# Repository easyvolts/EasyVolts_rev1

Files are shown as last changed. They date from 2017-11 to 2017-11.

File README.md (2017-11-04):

# EasyVolts_rev1
repository for EasyVolts_rev1 device. EasyVolts is a tiny variable power supply with embedded "USB-to-serial" adapter for both UART and RS-485 interfaces which is controlled and powered entirely by USB (over Virtual COM port). It's not only a simple and convenient tool, but it also can be used as a universal bridge between PC software and the "real" world (for example it can be very handy in smart home systems where RS485 and 12v power supply are widely used). This project failed campaign on the IndieGoGo (https://www.indiegogo.com/projects/easyvolts-usb-powered-and-controlled-power-supply#/) so now its sources are made open to share my expirience and ideas among hobbyists.

Hopefully, in future I'll try to launch next generation of the project, with output voltage up to 24v, configurable GPIO/PWM outputs and USB3.0 support (it would be good to have more power). For more details check my web site www.easyvolts.com

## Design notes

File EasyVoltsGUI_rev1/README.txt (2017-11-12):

EasyVoltsGUI is a convenient UI for EasyVolts device. It provides convenient setup of voltage and current limit and easily readable measured load voltage and current.
This is a Python3.5.2 project. UI is build with help of wxFormBuilder 3.6.0 (*.fbp file). Generated by the builder software in in EasyVoltsGUI.py file. Business logic is locted in EasyVoltsGUI.pyw file.

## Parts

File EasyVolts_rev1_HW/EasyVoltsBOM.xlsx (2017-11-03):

Value | RefDes | Pattern | Name
0.2 | R8 | RES_0805 | RES_0805
100nF 25v | C5 | CAP_0603 | CAP_0603
100nF 25v | C6 | CAP_0603 | CAP_0603
100nF 25v | C7 | CAP_0603 | CAP_0603
100nF 25v | C8 | CAP_0603 | CAP_0603
100nF 25v | C9 | CAP_0603 | CAP_0603
100uF 25v | C1 | CAPAE-6.6x6.6h7.9 | CAPAE_6.6x6.6h7.9
10uF 10v | C4 | CAP_1206 | CAP_1206
10uF 25v | C2 | CAP_1206 | CAP_1206
10uF 25v | C3 | CAP_1206 | CAP_1206
1k | R7 | RES_0603 | RES_0603
1k 1% | R1 | RES_0603 | RES_0603
1k 1% | R3 | RES_0603 | RES_0603
1k 1% | R5 | RES_0603 | RES_0603
1k 1% | R9 | RES_0603 | RES_0603
33uH | L1 | SRN6045 | SRN6045
3k3 1% | R2 | RES_0603 | RES_0603
3k3 1% | R4 | RES_0603 | RES_0603
3k3 1% | R6 | RES_0603 | RES_0603
3k3 1% | R10 | RES_0603 | RES_0603
3k3 1% | R11 | RES_0603 | RES_0603
green | D3 | HSM-C170 | HSMQ-C170
NC | J2 | HDR-1x5T/1.27/6x2 | GRPB051VWVN
 | D1 | DIOM_5.4x3.62 | SS24
 | D2 | DIOM_5.1x2.67 | SS12
 | D4 | SOT23 | PESD2CAN
NC | J1 | HDR-1x6T/2.54/15x2 | 644456-6
 | J3 | MC32603 | MC32603
 | Q1 | SOT23 | IRLML9301
 | Q2 | SOT23 | IRLML6346
 | U1 | SOIC-14/150mil | PIC16F1455_SL
 | U2 | SOIC-8/150mil | ISL31472

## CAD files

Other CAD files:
EasyVolts_rev1_MPLAB.X/dist/default/production/EasyPowerUSB.X.production.obj

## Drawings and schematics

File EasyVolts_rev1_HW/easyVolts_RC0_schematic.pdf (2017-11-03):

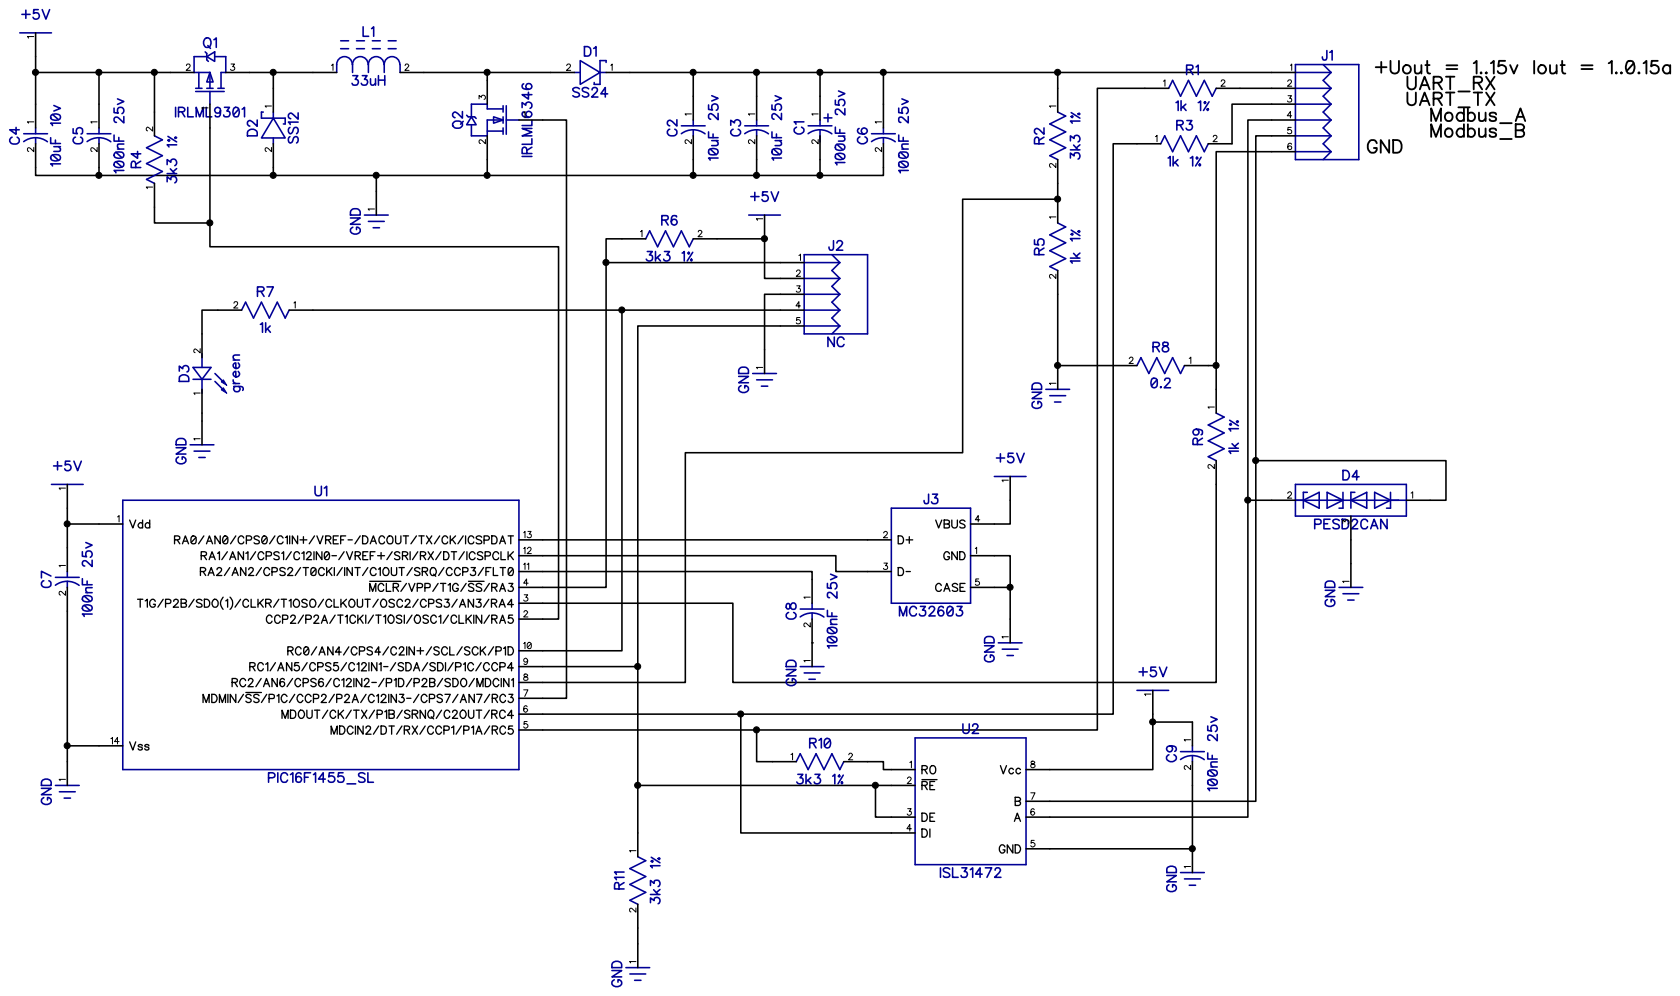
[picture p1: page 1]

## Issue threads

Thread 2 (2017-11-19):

USB2.0 USB Power limitation

tigerwang202, 2017-11-19:
Due to 500mA maximum current limitation from USB 2.0 specification, the Max output current  1A is impossible, unless using an auxiliary 5v power supply.

easyvolts, 2017-11-19:
This is not correct. 1a current is reachable when EasyVolts is in stepDown mode (output voltage is <5v). For example at 1v8 output voltage 1a can be reached (max input power is 2.5w, output power at 1v8 can be 1.8w = 1v8*1a).

tigerwang202, 2017-11-20:
So we need some current limitation method to make sure the VBus current doesn't exceed specification, maybe current monitor(like TI's INA180) connected to MCU's ADC channel?

easyvolts, 2017-11-20:
It's already in the code. Software monitors current (by measuring a voltage on the shunt resistor) and starts reducing output voltage when current goes higher than the limit. The limit can be set by iXXX\r\n command over terminal. If the user tries to set too high power limit - it will be limited inside of the firmware to keep output power <=2.2w(don't remember the exact value). So power consumption from USB is limited. There is only one detail that could be improved - efficiency of the system is not the same for different output voltages, so it would be good to test efficiency in complete output voltage range to create a table that would specify max output power for each output voltage taking into account efficiency of the DCDC. This would guaranty that we will limit power consumption from USB at an appropriate level.

Closed 2017-11-26.

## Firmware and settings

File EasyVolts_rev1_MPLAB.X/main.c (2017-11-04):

/*******************************************************************************
Copyright 2016 Microchip Technology Inc. (www.microchip.com)

Licensed under the Apache License, Version 2.0 (the "License");
you may not use this file except in compliance with the License.
You may obtain a copy of the License at

    http://www.apache.org/licenses/LICENSE-2.0

Unless required by applicable law or agreed to in writing, software
distributed under the License is distributed on an "AS IS" BASIS,
WITHOUT WARRANTIES OR CONDITIONS OF ANY KIND, either express or implied.
See the License for the specific language governing permissions and
limitations under the License.

To request to license the code under the MLA license (www.microchip.com/mla_license), 
please contact mla_licensing@microchip.com
*******************************************************************************/
// This software implements EasyVolt logic (composit USB CDC device made of 2 
// CDC ACM profiles, one to control power converter, second - to be used as 
// USB-UART/RS485 converter).
// Created by: Valerii Proskurin.
// Date: Feb 2017. 

/** INCLUDES *******************************************************/
#include "system.h"

#include "app_uart_usb_utils.h"

#include "usb.h"
#include "usb_device.h"
#include "usb_device_cdc.h"
#include "mcc_generated_files/mcc.h"
#include <stdlib.h>

//#define PWM_TEST
#define PWM_PERIOD              (188)// (333)//142kHz. (283)//166kHz, (237) //200KHz, (187)//250kHz, (93)//500KHz,
#define PWM_PERIOD_LIMIT        (PWM_PERIOD)

#define MAX_POWER_mWt           (2400000U)

#define MAX_UOUT_mV             (15000U)
#define MIN_UOUT_mV             (0U)

#define MAX_IOUT_mA             (1000U)
#define MIN_IOUT_mA             (0U)

uint8_t PwmDutyCycleVoltageLimit = 0, PwmDutyCycleCurrentLimit = 0;
volatile uint16_t Uadc = 0, Iadc = 0;
uint16_t Iadc_limit = 0, Uadc_target = 0;

int32_t MAIN_Uout_target_mV = 0;
int32_t MAIN_Iout_limit_mA = 500;

static uint16_t MAIN_Uout_mV = 0;
static uint16_t MAIN_Iout_mA = 0;
static int8_t MAIN_ovcFlag = 0, MAIN_upConverterFlag = 0;

static uint8_t readBuffer[CDC_DATA_OUT_EP_SIZE];
static uint8_t writeBuffer[CDC_DATA_IN_EP_SIZE];
static uint8_t writeStatusBuffer[CDC_DATA_IN_EP_SIZE];
static uint8_t cmdRxBuffer[CDC_DATA_OUT_EP_SIZE];

static const uint8_t errorMsg[] = "Wrong cmd!\r\n";
static const uint8_t okMsg[] = "OK\r\n";

static uint8_t USB_Out_Buffer[CDC_DATA_OUT_EP_SIZE];
static uint8_t RS232_Out_Data[CDC_DATA_IN_EP_SIZE];
unsigned char  NextUSBOut;
unsigned char  NextUSBOut;
unsigned char  LastRS232Out;  // Number of characters in the buffer
unsigned char  RS232cp;       // current position within the buffer
unsigned char  RS232_Out_Data_Rdy = 0;

//we use stepDown for voltages 0..5v, stepUp for 5..15v
void main_switchStepUp_Down(int32_t Uout_mV)
{
   //disable power
   RA5_SetHigh();
   //adjust PWM
   if(Uout_mV <= 4500) { 
        PwmDutyCycleVoltageLimit = (PWM_PERIOD*(350+Uout_mV))/(5000);//use larger PWM due to losses in coil and diod
        PWM2_LoadDutyValue(0);
        PWM2CON = 0xD0; //active LOW
        APFCON = 0x04;
        MAIN_upConverterFlag = 0;
    } else if(Uout_mV <= 4850) {
        PwmDutyCycleVoltageLimit = 1;
        PWM2_LoadDutyValue(0);
        PWM2CON = 0xC0; //active HIGH
        APFCON = 0x00;
        MAIN_upConverterFlag = 1;
        RA5_SetLow();//enable power output
    } else {
        PwmDutyCycleVoltageLimit = 2 + ((PWM_PERIOD*(Uout_mV - 4850))/(Uout_mV));
        PWM2_LoadDutyValue(0);
        PWM2CON = 0xC0; //active HIGH
        APFCON = 0x00;
        MAIN_upConverterFlag = 1;
        RA5_SetLow();//enable power output
    }
}

void main_CDC_to_RS485_Initialize()
{   
    unsigned char i;
    
    line_coding2.bCharFormat = 0;
    line_coding2.bDataBits = 8;
    line_coding2.bParityType = 0;
    line_coding2.dwDTERate = 9600;

// 	 Initialize the arrays
	for (i=0; i<sizeof(USB_Out_Buffer); i++)
    {
		USB_Out_Buffer[i] = 0;
    }

	NextUSBOut = 0;
	LastRS232Out = 0;
}

#define mDataRdyUSART()         PIR1bits.RCIF
#define mTxRdyUSART()           TXSTAbits.TRMT

void main_CDC_to_RS485_Tasks()
{
    /* If the USB device isn't configured yet, we can't really do anything
     * else since we don't have a host to talk to.  So jump back to the
     * top of the while loop. */
    if( USBGetDeviceState() < CONFIGURED_STATE )
    {
        return;
    }

    /* If we are currently suspended, then we need to see if we need to
     * issue a remote wakeup.  In either case, we shouldn't process any
     * keyboard commands since we aren't currently communicating to the host
     * thus just continue back to the start of the while loop. */
    if( USBIsDeviceSuspended()== true )
    {
        return;
    }

//    /* Check to see if there is a transmission in progress, if there isn't, then
//     * we can see about performing an echo response to data received.
//     */
//    if( USBUSARTIsTxTrfReady2() == true)
//    {
//        uint8_t i;
//        uint8_t numBytesRead;
//
//        numBytesRead = getsUSBUSART2(readBufferRS485, sizeof(readBufferRS485));
//
//        //for test only!!!!
//        if(numBytesRead > 0)
//        {
//            memcpy(writeBufferRS485,readBufferRS485, numBytesRead);
//            /* send out the "echo" data now.
//             */
//            putUSBUSART2(writeBufferRS485,numBytesRead);
//        }
//    }

    if (RS232_Out_Data_Rdy == 0)  // only check for new USB buffer if the old RS232 buffer is
	{						      // empty.  This will cause additional USB packets to be NAK'd
		LastRS232Out = getsUSBUSART2(RS232_Out_Data,64); //until the buffer is free.
		if(LastRS232Out > 0)
		{
			RS232_Out_Data_Rdy = 1;  // signal buffer full
			RS232cp = 0;  // Reset the current position
            IO_RC1_SetHigh(); //Set TXE signal for RS485
		} else {
            if(mTxRdyUSART()) IO_RC1_SetLow(); //Reset TXE signal for RS485
        }
	}

    
    //Check if one or more bytes are waiting in the physical UART transmit
    //queue.  If so, send it out the UART TX pin.
	if(RS232_Out_Data_Rdy && mTxRdyUSART())
	{
	        //Hardware flow control not being used.  Just send the data.
    		USART_putcUSART(RS232_Out_Data[RS232cp]);
    		++RS232cp;
    		if (RS232cp == LastRS232Out) {
                RS232_Out_Data_Rdy = 0;
            }
	}

    //Check if we received a character over the physical UART, and we need
    //to buffer it up for eventual transmission to the USB host.
	if(mDataRdyUSART() && (NextUSBOut < (CDC_DATA_OUT_EP_SIZE - 1)))
        {
		USB_Out_Buffer[NextUSBOut] = USART_getcUSART();
		++NextUSBOut;
		USB_Out_Buffer[NextUSBOut] = 0;
	}

    //Check if any bytes are waiting in the queue to send to the USB host.
    //If any bytes are waiting, and the endpoint is available, prepare to
    //send the USB packet to the host.
	if((USBUSARTIsTxTrfReady2()) && (NextUSBOut > 0))
	{
		putUSBUSART2(&USB_Out_Buffer[0], NextUSBOut);
		NextUSBOut = 0;
	}
    
    CDCTxService2();
}


void main_SetDcDcRegulator(int32_t * pU_mV, int32_t * pI_mA)
{
    //limit voltage
    if((*pU_mV) > MAX_UOUT_mV) (*pU_mV) = MAX_UOUT_mV;
    if((*pU_mV) < MIN_UOUT_mV) (*pU_mV) = MIN_UOUT_mV;
    //limit current
    if((*pI_mA) > MAX_IOUT_mA) (*pI_mA) = MAX_IOUT_mA;
    if((*pI_mA) < MIN_IOUT_mA) (*pI_mA) = MIN_IOUT_mA;
    
    //limit DC-DC power due to USB limitations
    if(((*pU_mV)*(*pI_mA)) > MAX_POWER_mWt) {
        *pI_mA = MAX_POWER_mWt/(*pU_mV);
    }
    
    //adjust dc-dc regulation limits
    //switch between step Up/Down modes
    INTERRUPT_PeripheralInterruptDisable();
    main_switchStepUp_Down(*pU_mV);
    Iadc_limit = 3+(*pI_mA)/10;
    Uadc_target = (100*(50+*pU_mV))/1761;//17.61v per 1024steps
    INTERRUPT_PeripheralInterruptEnable();
    MAIN_ovcFlag = 0;
}

// Implementation of itoa()
const uint16_t dividerArray[5][9] = { 
    {1,2,3,4,5,6,7,8,9},
    {10,20,30,40,50,60,70,80,90},
    {100,200,300,400,500,600,700,800,900},
    {1000,2000,3000,4000,5000,6000,7000,8000,9000},
    {10000,20000,30000,40000,50000,60000,0,0,0} }; //we have up to 65535 input number
    
void my_uitoa(char* str, uint16_t num)
{
    int8_t powerOfTen, ziffer = 5;
    uint8_t strIncremet = 0;

    for(powerOfTen=4; powerOfTen>=0; powerOfTen--) {
        *str = '0';
        for(; ziffer>=0; ziffer--) {            
            if(num > dividerArray[powerOfTen][ziffer]) {
                strIncremet = 1;
                *str += ziffer+1;
                num -= dividerArray[powerOfTen][ziffer];
                break;
            }
        }
        ziffer=8;
        str+=strIncremet;
    }
    
}

void main_Communication_Initialize(void)
{
    unsigned char i;
    
    line_coding.bCharFormat = 0;
    line_coding.bDataBits = 8;
    line_coding.bParityType = 0;
    line_coding.dwDTERate = 9600;

    // clear the TMR1 interrupt flag
    TMR1IF = 0;
    // Reload the initial value of TMR1
    TMR1_Reload();
    
    // 	 Initialize the arrays
	for (i=0; i<sizeof(writeBuffer); i++)
    {
		writeBuffer[i] = 0;
    }    
}

void main_CommunicationHandler()
{
    static uint8_t step = 0;
    static uint8_t cmdRxBufferPointer = 0;
    /* If the USB device isn't configured yet, we can't really do anything
     * else since we don't have a host to talk to.  So jump back to the
     * top of the while loop. */
    if( USBGetDeviceState() < CONFIGURED_STATE )
    {
        return;
    }

    /* If we are currently suspended, then we need to see if we need to
     * issue a remote wakeup.  In either case, we shouldn't process any
     * keyboard commands since we aren't currently communicating to the host
     * thus just continue back to the start of the while loop. */
    if( USBIsDeviceSuspended()== true )
    {
        return;
    }

    /* Check to see if there is a transmission in progress, if there isn't, then
     * we can see about performing an echo response to data received.
     */
    if( USBUSARTIsTxTrfReady() == true)
    {
        uint8_t i;
        uint8_t numBytesRead;

        numBytesRead = getsUSBUSART(readBuffer, sizeof(readBuffer));

        if(numBytesRead) {
            /* For every byte that was read... */
            for(i=0; i<numBytesRead; i++)
            {
                cmdRxBuffer[cmdRxBufferPointer] = readBuffer[i];
                if((0x0A == cmdRxBuffer[cmdRxBufferPointer]) || (0x0D == cmdRxBuffer[cmdRxBufferPointer]))
                {
                    //execute command here
                    if(('U' == cmdRxBuffer[0]) || ('u' == cmdRxBuffer[0])) {
                        MAIN_Uout_target_mV = atoi(&cmdRxBuffer[1]);
//                        memcpy(writeBuffer,okMsg,sizeof(okMsg));
//                        putUSBUSART(writeBuffer,sizeof(okMsg)-1);
                        main_SetDcDcRegulator(&MAIN_Uout_target_mV, &MAIN_Iout_limit_mA);
                        if(MAIN_Uout_target_mV) IO_RC0_SetHigh();
                        else IO_RC0_SetLow();
                    } else if(('I' == cmdRxBuffer[0]) || ('i' == cmdRxBuffer[0])) {
                        MAIN_Iout_limit_mA = atoi(&cmdRxBuffer[1]);                        
//                        memcpy(writeBuffer,okMsg,sizeof(okMsg));
//                        putUSBUSART(writeBuffer,sizeof(okMsg)-1);
                        main_SetDcDcRegulator(&MAIN_Uout_target_mV, &MAIN_Iout_limit_mA);
                        if(MAIN_Uout_target_mV) IO_RC0_SetHigh();
                        else IO_RC0_SetLow();
                    } else {
                        memcpy(writeBuffer,errorMsg,sizeof(errorMsg));
                        putUSBUSART(writeBuffer,sizeof(errorMsg)-1);
                    }
                    //reset buffer
                    cmdRxBufferPointer = 0;
                    memset(cmdRxBuffer,0,sizeof(cmdRxBuffer));
                    break;
                }
                cmdRxBufferPointer++;
                //check buffer overflow
                if(sizeof(cmdRxBuffer) < cmdRxBufferPointer) {
                    cmdRxBufferPointer = 0;
                    memset(cmdRxBuffer,0,sizeof(cmdRxBuffer));
                    break;
                }
            }
        } else if(TMR1IF) {
            switch (step){
            case 0:
                MAIN_Uout_mV = (1761*(uint32_t)Uadc)/100;
                MAIN_Iout_mA = Iadc*10;
                step++;
                break;
            case 1:                    
                writeStatusBuffer[0] = 0;
                memcpy(writeStatusBuffer,"EasyVolts \tU(mV)=      \t I(mA)=     \r\n", 38/*+5*/);
                step++;
                break;
            case 2:                    
                my_uitoa(&writeStatusBuffer[17],MAIN_Uout_mV);//voltage
                step++;
                break;
            case 3:
                my_uitoa(&writeStatusBuffer[31],MAIN_Iout_mA);//current  
//                my_uitoa(&writeStatusBuffer[36],PwmDutyCycle);
                step++;
                break;
            default:
                //handle led and special symbols
                switch(MAIN_ovcFlag){
                    case 0:
                        if(0 == MAIN_Uout_target_mV) {
                            IO_RC0_SetLow();//switch off led and print "_" if output is OFF
                            writeStatusBuffer[24] = '_';
                        } else IO_RC0_SetHigh();
                        break;
                    case 1:
                        IO_RC0_Toggle();//blink led and print "^" if overcurrent
                        writeStatusBuffer[24] = '^';
                        break;
                    default:
                        IO_RC0_SetLow();//switch off led and print "!" if overcurrent error
                        writeStatusBuffer[24] = '!';
                        break;
                }
                putUSBUSART(writeStatusBuffer,38/*+5*/);
                // clear the TMR1 interrupt flag
                TMR1IF = 0;
                // Reload the initial value of TMR1
                TMR1_Reload();
                step = 0;
                break;
            }
        }
    }

    CDCTxService();
}

void main_overcurrentProtection()
{
    static uint8_t tOut = 0;
    static Iadc_avg = 0;
    
    Iadc_avg = ((Iadc_avg + Iadc)>>1);
    
    if((Iadc_avg <= Iadc_limit)&&(2 != MAIN_ovcFlag)) {
        if(PwmDutyCycleCurrentLimit < PWM_PERIOD) PwmDutyCycleCurrentLimit++;
        else MAIN_ovcFlag = 0;
    } else {
        if(PwmDutyCycleCurrentLimit > 0) {
            PwmDutyCycleCurrentLimit--;
        } else {
            if(tOut > 100) {
                tOut = 0;
                //disable power
                RA5_SetHigh();
                MAIN_ovcFlag = 2;
            } else {
                tOut++;
            }
        }      
    }
}
/********************************************************************
 * Function:        void main(void)
 *
 * PreCondition:    None
 *
 * Input:           None
 *
 * Output:          None
 *
 * Side Effects:    None
 *
 * Overview:        Main program entry point.
 *
 * Note:            None
 *******************************************************************/
MAIN_RETURN main(void)
{
    SYSTEM_Initialize();
    TMR1_StartTimer();
//    TMR0_Reload();
    INTERRUPT_GlobalInterruptEnable();
    INTERRUPT_PeripheralInterruptEnable();
    ADC_StartConversion();
    
    USBDeviceInit();
    USBDeviceAttach();
    
    main_SetDcDcRegulator(&MAIN_Uout_target_mV, &MAIN_Iout_limit_mA);
    
    while(1)
    {
        SYSTEM_Tasks();
//        #if defined(USB_POLLING)
//            // Interrupt or polling method.  If using polling, must call
//            // this function periodically.  This function will take care
//            // of processing and responding to SETUP transactions
//            // (such as during the enumeration process when you first
//            // plug in).  USB hosts require that USB devices should accept
//            // and process SETUP packets in a timely fashion.  Therefore,
//            // when using polling, this function should be called
//            // regularly (such as once every 1.8ms or faster** [see
//            // inline code comments in usb_device.c for explanation when
//            // "or faster" applies])  In most cases, the USBDeviceTasks()
//            // function does not take very long to execute (ex: <100
//            // instruction cycles) before it returns.
//            USBDeviceTasks();
//        #endif
        //Application specific tasks   
        main_overcurrentProtection();
        main_CommunicationHandler();
        CLRWDT();             
    }//end while
}//end main

/*******************************************************************************
 End of File
*/

void interrupt INTERRUPT_InterruptManager(void)
{
    static int8_t pwmCorrection = 0;
    uint16_t pwm;
    
    Uadc = (Uadc + ADC_GetConversionResult() - (Iadc>>1))>>1;
    FVRCON = 0x82; //switch Vref for adc to 2.048v and start I measurement
    ADC_SelectChannel(channel_AN3);
    if(MAIN_upConverterFlag) pwmCorrection = ((pwmCorrection<<2) + Iadc)>>3;
    else pwmCorrection = ((pwmCorrection<<1) + Iadc)>>2;
   
    if((Uadc > Uadc_target) || (2 == MAIN_ovcFlag)) {
        PWM2_LoadDutyValue(0);
    } else {
        pwm = PwmDutyCycleVoltageLimit+pwmCorrection;
        if(pwm > PWM_PERIOD_LIMIT) pwm = PWM_PERIOD_LIMIT;
        if(pwm > PwmDutyCycleCurrentLimit) {
            pwm = PwmDutyCycleCurrentLimit;
            MAIN_ovcFlag = 1;
        }
        PWM2_LoadDutyValue(pwm);
    }
        

    ADC_StartConversion();  
    main_CDC_to_RS485_Tasks();
    while(false == ADC_IsConversionDone());
    Iadc = ADC_GetConversionResult();
    FVRCON = 0x83;
    ADC_SelectChannel(channel_AN6);
    USBDeviceTasks();
    ADC_StartConversion();        
        
    // Clear the ADC interrupt flag
    PIR1bits.ADIF = 0; 
}

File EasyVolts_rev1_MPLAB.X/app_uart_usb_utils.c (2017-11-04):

/*******************************************************************************
Copyright 2016 Microchip Technology Inc. (www.microchip.com)

Licensed under the Apache License, Version 2.0 (the "License");
you may not use this file except in compliance with the License.
You may obtain a copy of the License at

    http://www.apache.org/licenses/LICENSE-2.0

Unless required by applicable law or agreed to in writing, software
distributed under the License is distributed on an "AS IS" BASIS,
WITHOUT WARRANTIES OR CONDITIONS OF ANY KIND, either express or implied.
See the License for the specific language governing permissions and
limitations under the License.

To request to license the code under the MLA license (www.microchip.com/mla_license), 
please contact mla_licensing@microchip.com
*******************************************************************************/

// *****************************************************************************
// *****************************************************************************
// Section: Included Files
// *****************************************************************************
// *****************************************************************************
#include <stdint.h>
#include "mcc_generated_files/mcc.h"
#include "usb_device_cdc.h"


// *****************************************************************************
// *****************************************************************************
// Section: File Scope or Global Constants
// *****************************************************************************
// *****************************************************************************


// *****************************************************************************
// *****************************************************************************
// Section: File Scope Data Types
// *****************************************************************************
// *****************************************************************************


// *****************************************************************************
// *****************************************************************************
// Section: Macros or Functions
// *****************************************************************************
// *****************************************************************************

/******************************************************************************
 * Function:        void USART_putcUSART(char c)
 *
 * PreCondition:    None
 *
 * Input:           char c - character to print to the UART
 *
 * Output:          None
 *
 * Side Effects:    None
 *
 * Overview:        Print the input character to the UART
 *
 * Note:
 *
 *****************************************************************************/
void USART_putcUSART(char c)
{
      TXREG = c;
}


/******************************************************************************
 * Function:        void USART_mySetLineCodingHandler(void)
 *
 * PreCondition:    USB_CDC_SET_LINE_CODING_HANDLER is defined
 *
 * Input:           None
 *
 * Output:          None
 *
 * Side Effects:    None
 *
 * Overview:        This function gets called when a SetLineCoding command
 *                  is sent on the bus.  This function will evaluate the request
 *                  and determine if the application should update the baudrate
 *                  or not.
 *
 * Note:
 *
 *****************************************************************************/
#if defined(USB_CDC_SET_LINE_CODING_HANDLER2)
void USART_mySetLineCodingHandler(void)
{
    //If the request is not in a valid range
    //if(cdc_notice.GetLineCoding.dwDTERate > 115200)
    //{
        //NOTE: There are two ways that an unsupported baud rate could be
        //handled.  The first is just to ignore the request and don't change
        //the values.  That is what is currently implemented in this function.
        //The second possible method is to stall the STATUS stage of the request.
        //STALLing the STATUS stage will cause an exception to be thrown in the
        //requesting application.  Some programs, like HyperTerminal, handle the
        //exception properly and give a pop-up box indicating that the request
        //settings are not valid.  Any application that does not handle the
        //exception correctly will likely crash when this requiest fails.  For
        //the sake of example the code required to STALL the status stage of the
        //request is provided below.  It has been left out so that this demo
        //does not cause applications without the required exception handling
        //to crash.
        //---------------------------------------
        //USBStallEndpoint(0,1);
    //}
    //else
    //{
        //Update the baudrate info in the CDC driver
        CDCSetBaudRate2(cdc_notice2.GetLineCoding.dwDTERate);
        //Update the baudrate of the UART
        uint32_t dwBaud;
        dwBaud = ((_XTAL_FREQ/4) / line_coding2.dwDTERate) - 1;
        SPBRG = (uint8_t) dwBaud;
        SPBRGH = (uint8_t)((uint16_t) (dwBaud >> 8));
    //}
}
#endif

/******************************************************************************
 * Function:        void USART_getcUSART(char c)
 *
 * PreCondition:    None
 *
 * Input:           None
 *
 * Output:          unsigned char c - character to received on the UART
 *
 * Side Effects:    None
 *
 * Overview:        Print the input character to the UART
 *
 * Note:
 *
 *****************************************************************************/
unsigned char USART_getcUSART ()
{
	char  c;

	if (RCSTAbits.OERR)  // in case of overrun error
	{                    // we should never see an overrun error, but if we do,
		RCSTAbits.CREN = 0;  // reset the port
		c = RCREG;
		RCSTAbits.CREN = 1;  // and keep going.
	}
	else
    {
		c = RCREG;
    }
// not necessary.  EUSART auto clears the flag when RCREG is cleared
//	PIR1bits.RCIF = 0;    // clear Flag

  
	return c;
}

/*******************************************************************************
 End of File
*/

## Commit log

2017-11-03 Hardware files upload
    Uploaded hardware files (schematic, BOM and gerber files) of EasyVolts_rev1 project
    [EasyVoltsBOM.xlsx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]
2017-11-03 Add firmware project of EasyVolts_rev1 for MPLABX
    The project implements the internal logic of EasyVolts. It controls DC-DC stepUp/stepDown converter, USB communication with host PC and RS485 driver.
2017-11-03 added PCB file for DipTrace
2017-11-03 Upload correct PCB project file for DipTrace
2017-11-04 Upload MPLABX firmware project
    [EasyPowerUSB.X.production.obj]
2017-11-04 Add schematic for DipTrace
